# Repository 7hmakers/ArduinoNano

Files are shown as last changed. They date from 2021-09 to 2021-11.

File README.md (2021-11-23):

# ArduinoNano
A Development Board based on ATMEGA328P, compatible with Arduino Nano

Made for FZYZ 7HMakers Club






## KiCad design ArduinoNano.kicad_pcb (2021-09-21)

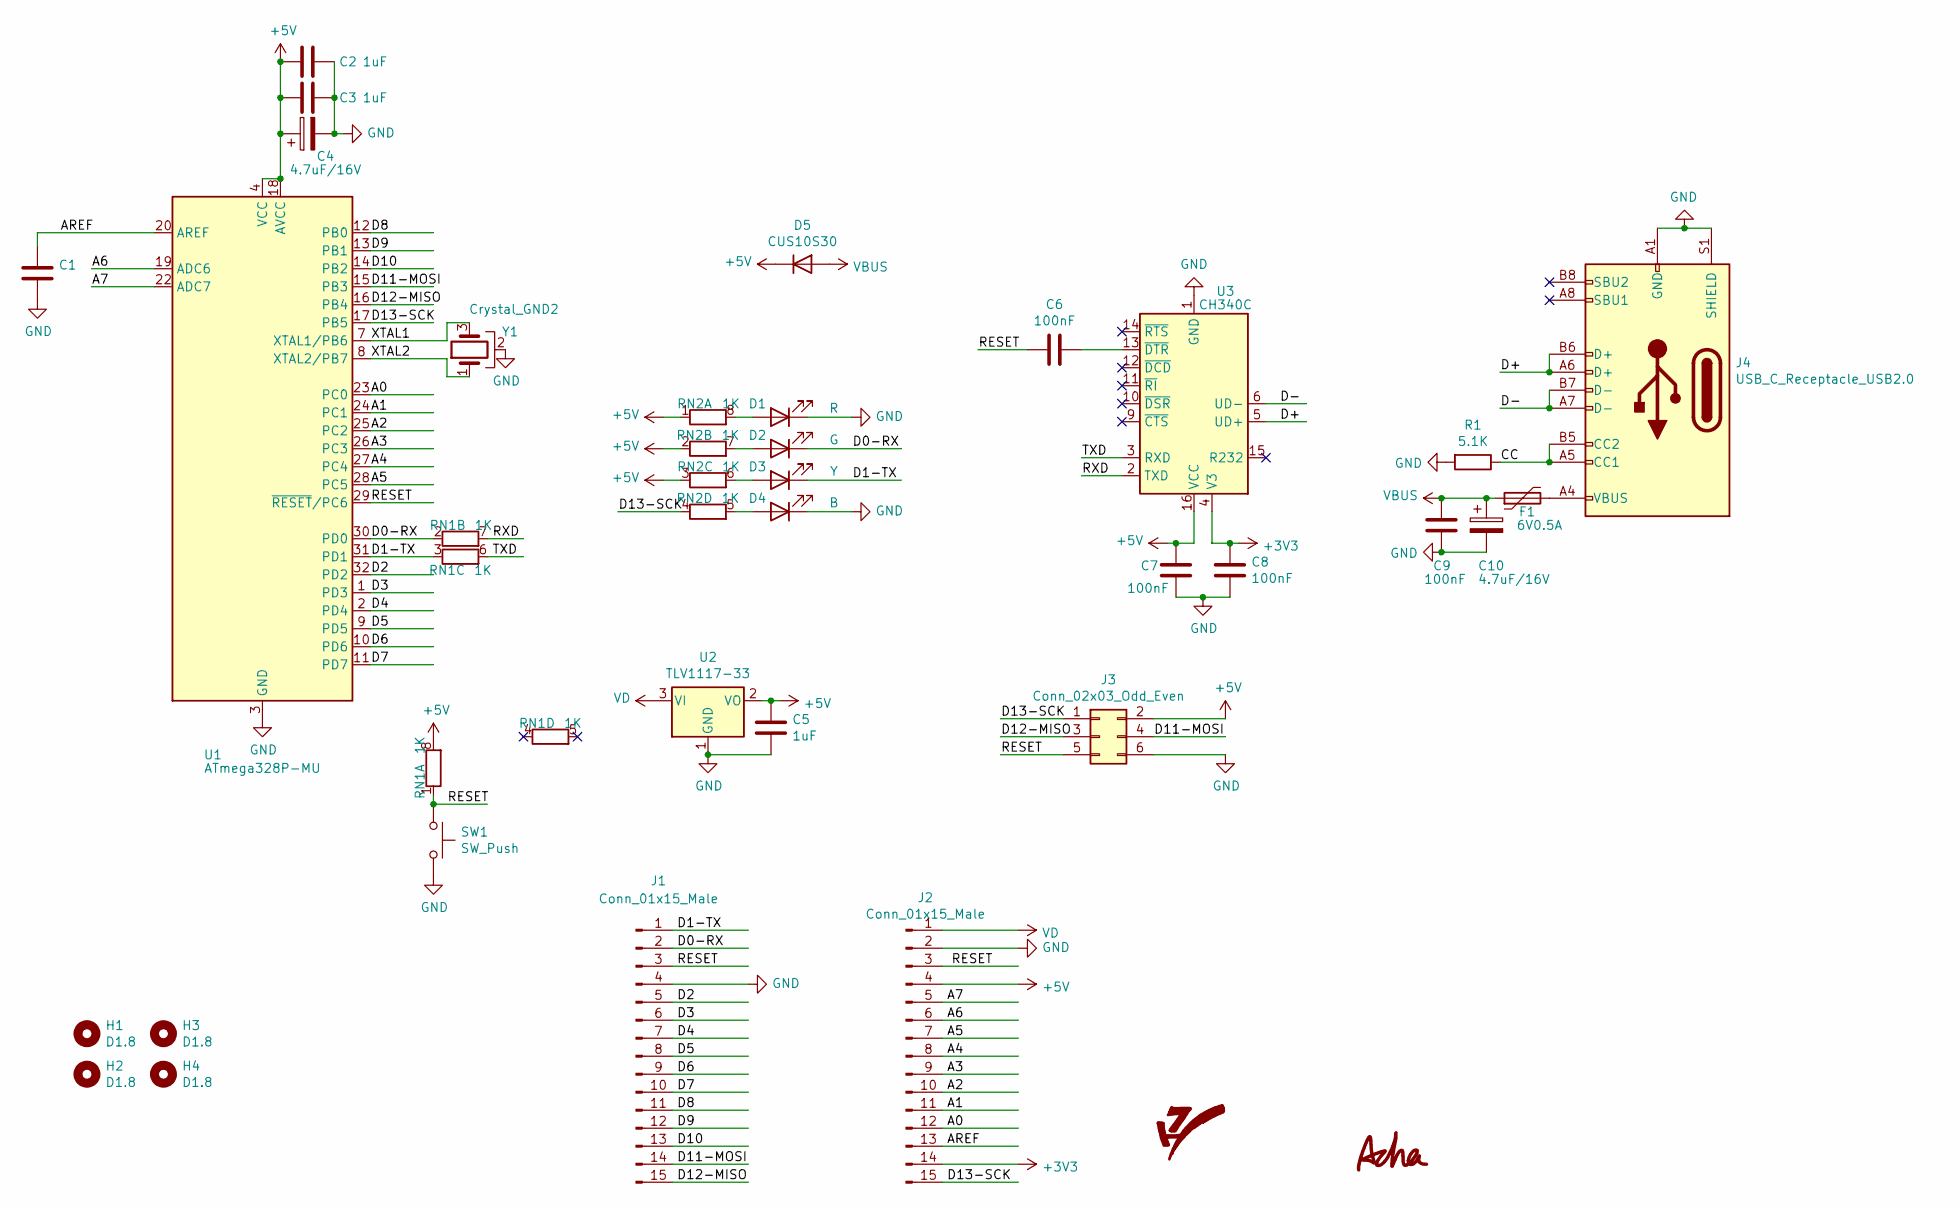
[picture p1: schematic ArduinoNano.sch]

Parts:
C1, C6, C7, C8, C9: 100nF; C_0603_1608Metric
C2, C3, C5: 1uF; C_0603_1608Metric
C4, C10: 4.7uF/16V; CP_EIA-3216-18_Kemet-A
D1: R; LED_0603_1608Metric
D2: G; LED_0603_1608Metric
D3: Y; LED_0603_1608Metric
D4: B; LED_0603_1608Metric
D5: CUS10S30; D_SOD-323
F1: 6V0.5A; Fuse_0603_1608Metric
G1: 7Maker_LOGO_SCH_10.8x10.8; 7Maker_LOGO_9.6x9.6
G2: LOGO; Acha_LOGO_5.2x3
H1, H2, H3, H4: D1.8; MountingHole_1.8mm
J1, J2: Conn_01x15_Male; PinHeader_1x15_P2.54mm_Vertical_ard
J3: Conn_02x03_Odd_Even; PinHeader_2x03_P2.54mm_Vertical
J4: USB_C_Receptacle_USB2.0; USB_C_Receptacle_XKB_U262-16XN-4BVC11
R1: 5.1K; R_0603_1608Metric
RN1, RN2: 1K; R_Array_Convex_4x0603
SW1: SW_Push; SW_Push_SPST_NO_Alps_SKRK
U1: ATmega328P-MU; QFN-32-1EP_5x5mm_P0.5mm_EP3.1x3.1mm
U2: TLV1117-33; TLV1117-15CDRJR
U3: CH340C; SOIC-16_3.9x9.9mm_P1.27mm
Y1: Crystal_GND2; Resonator_SMD_muRata_CSTxExxV-3Pin_3.0x1.1mm

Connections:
+3V3: C8.1, J2.14, U3.4 (V3)
+5V: C2.2, C3.2, C4.1, C5.1, C7.1, D5.1 (K), J2.4, J3.2, RN1.8 (R1.2), RN2.1 (R1.1), RN2.2 (R2.1), RN2.3 (R3.1), U1.4 (VCC), U1.6 (VCC), U1.18 (AVCC), U2.2 (VO), U3.16 (VCC)
/A0: J2.12, U1.23 (PC0)
/A1: J2.11, U1.24 (PC1)
/A2: J2.10, U1.25 (PC2)
/A3: J2.9, U1.26 (PC3)
/A4: J2.8, U1.27 (PC4)
/A5: J2.7, U1.28 (PC5)
/A6: J2.6, U1.19 (ADC6)
/A7: J2.5, U1.22 (ADC7)
/AREF: C1.1, J2.13, U1.20 (AREF)
/CC: J4.A5 (CC1), J4.B5 (CC2), R1.1
/D0-RX: D2.1 (K), J1.2, RN1.2 (R2.1), U1.30 (PD0)
/D1-TX: D3.1 (K), J1.1, RN1.3 (R3.1), U1.31 (PD1)
/D2: J1.5, U1.32 (PD2)
/D3: J1.6, U1.1 (PD3)
/D4: J1.7, U1.2 (PD4)
/D5: J1.8, U1.9 (PD5)
/D6: J1.9, U1.10 (PD6)
/D7: J1.10, U1.11 (PD7)
/D8: J1.11, U1.12 (PB0)
/D9: J1.12, U1.13 (PB1)
/D10: J1.13, U1.14 (PB2)
/D11-MOSI: J1.14, J3.4, U1.15 (PB3)
/D12-MISO: J1.15, J3.3, U1.16 (PB4)
/D13-SCK: J2.15, J3.1, RN2.4 (R4.1), U1.17 (PB5)
/D+: J4.A6 (D+), J4.B6 (D+), U3.5 (UD+)
/D-: J4.A7 (D-), J4.B7 (D-), U3.6 (UD-)
/RESET: C6.2, J1.3, J2.3, J3.5, RN1.1 (R1.1), SW1.1, U1.29 (~RESET~/PC6)
/RXD: RN1.7 (R2.2), U3.2 (TXD)
/TXD: RN1.6 (R3.2), U3.3 (RXD)
/XTAL1: U1.7 (XTAL1/PB6), Y1.3
/XTAL2: U1.8 (XTAL2/PB7), Y1.1
GND: C1.2, C2.1, C3.1, C4.2, C5.2, C7.2, C8.2, C9.2, C10.2, D1.1 (K), D4.1 (K), J1.4, J2.2, J3.6, J4.A1 (GND), J4.A12 (GND), J4.B1 (GND), J4.B12 (GND), J4.S1 (SHIELD), R1.2, SW1.2, U1.3 (GND), U1.5 (GND), U1.21 (GND), U1.33 (GND), U2.1 (GND), U3.1 (GND), Y1.2
unnamed: C6.1, U3.13 (~DTR)
unnamed: D1.2 (A), RN2.8 (R1.2)
unnamed: D2.2 (A), RN2.7 (R2.2)
unnamed: D3.2 (A), RN2.6 (R3.2)
unnamed: D4.2 (A), RN2.5 (R4.2)
unnamed: F1.2, J4.A4 (VBUS), J4.A9 (VBUS), J4.B4 (VBUS), J4.B9 (VBUS)
VBUS: C9.1, C10.1, D5.2 (A), F1.1
VD: J2.1, U2.3 (VI)

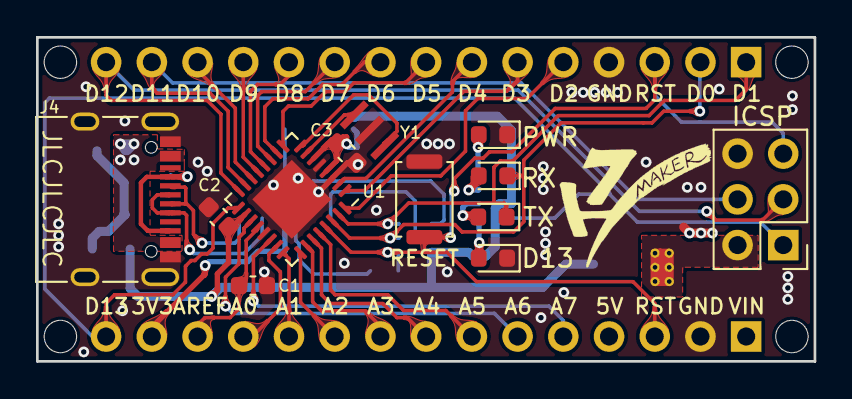
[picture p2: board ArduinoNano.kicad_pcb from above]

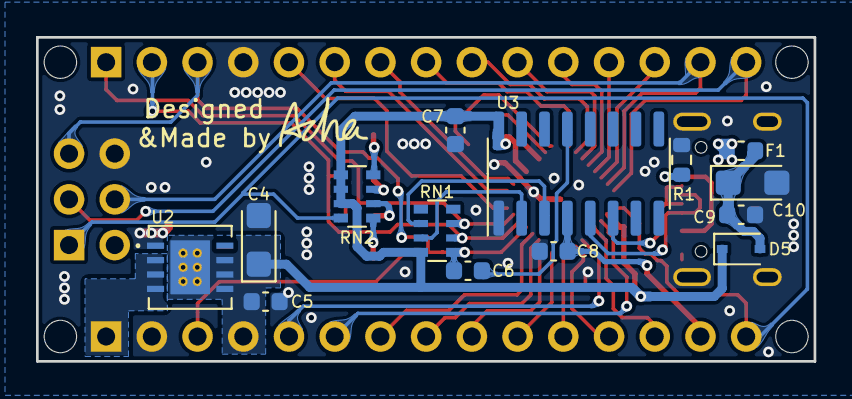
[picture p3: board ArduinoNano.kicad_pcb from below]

Board: 2 copper layers, 43.2 x 18.0 mm, 33 parts (15 on the bottom side), 42 nets.
